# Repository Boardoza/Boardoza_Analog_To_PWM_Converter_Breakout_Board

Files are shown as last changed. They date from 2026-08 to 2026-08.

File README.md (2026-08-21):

# Boardoza Analog To PWM Converter Breakout Board

The **Boardoza Analog to PWM Converter Breakout Board** is a high-precision signal conditioning board designed to convert an analog voltage input into a proportional **PWM (Pulse Width Modulation)** output signal where the **duty cycle increases or decreases proportionally with the applied input voltage**. Built using high-speed operational amplifiers and comparators, this board operates entirely through dedicated hardware circuitry, enabling ultra-fast response times and reliable signal conversion without requiring any firmware or software processing.

This breakout board is ideal for **motor control systems, throttle signal conversion, industrial automation, power electronics, robotics, and embedded analog control applications**. Its low-latency architecture and robust analog signal path make it suitable for safety-critical and noise-sensitive environments where deterministic signal behavior is essential.

## [Click here to purchase!](https://www.ozdisan.com/ureticiler/boardoza)

|Front Side|Back Side|
|:---:|:---:|
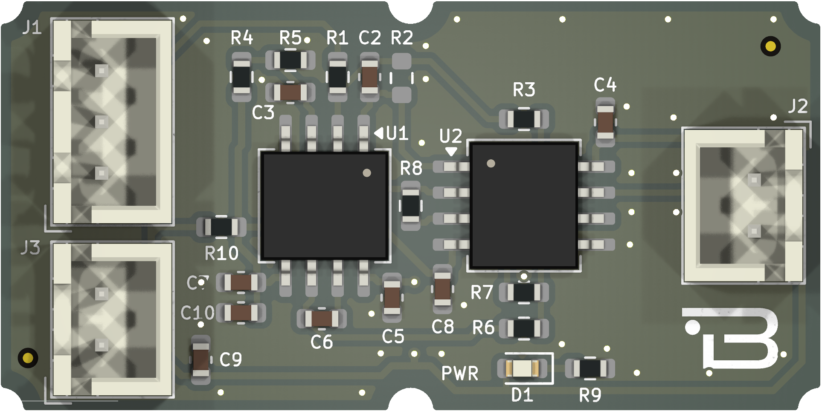
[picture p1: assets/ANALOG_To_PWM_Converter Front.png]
Analog-To-PWM Front
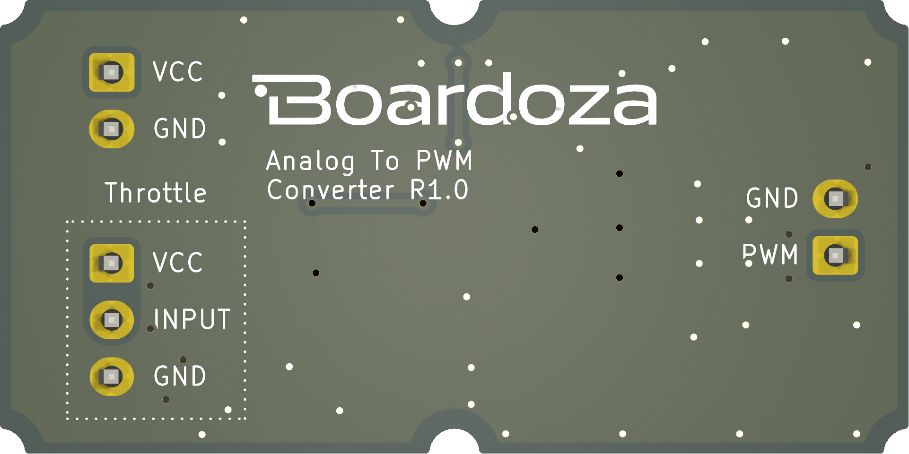
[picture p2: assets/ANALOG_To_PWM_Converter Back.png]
Analog-To-PWM Back
| | |

---

## Key Features

- **Hardware-Based PWM Generation:** Converts analog voltage signals directly into PWM output without requiring a microcontroller.
- **Discrete Analog Design:** Built using precision operational amplifiers and comparators for stable and deterministic operation.
- **Low Latency Signal Path:** Near-instantaneous analog-to-PWM conversion suitable for real-time control systems.
- **Push-Pull CMOS Output:** Provides strong and clean logic-level PWM output compatible with many digital systems.
- **High Noise Immunity:** Reliable operation in electrically noisy environments such as motor drivers and industrial systems.

---

## Technical Specifications

**Model:** Analog to PWM Converter  
**Manufacturer:** Boardoza   
**Manufacturer IC:** Texas Instruments   
**Operational Amplifier Model:** OPA2356  
**Board Type:** Analog Signal Converter    
**Input Voltage (VCC):** 2.7V – 5.5V  
**Analog Input Range:** 0.1V – 4.9V  
**Output Type:** 20kHz PWM (Push-Pull CMOS Logic)  
**Comparator Type:** High-Speed Comparator with Integrated Reference  
**Operational Amplifier Type:** Rail-to-Rail High-Speed Op-Amp  
**Output Short Circuit Current:** 74mA  
**Operating Temperature:** -40°C to +125°C  
**Board Dimensions:** 40mm x 20mm  v

---

## Simulation and Test Results

Simulation and test results are provided below.

| Triangle Wave Output | Error Amplifier Output | PWM Output |
|:---:|:---:|:---:|
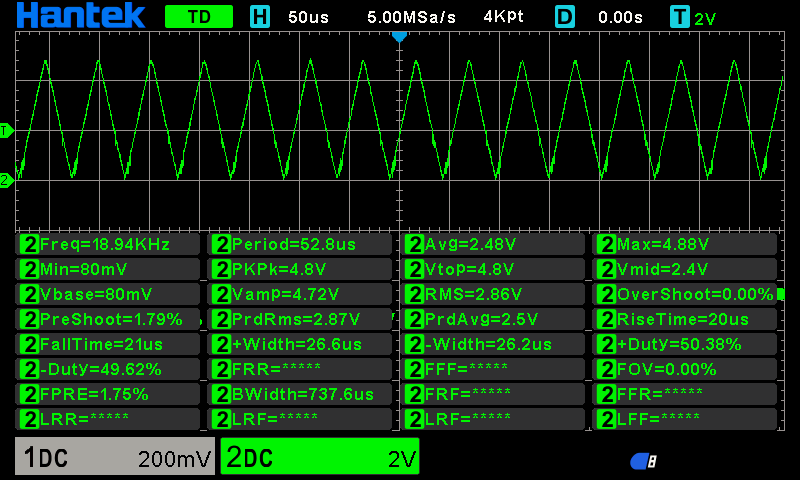
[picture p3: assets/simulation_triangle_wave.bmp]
Triangle Wave Output
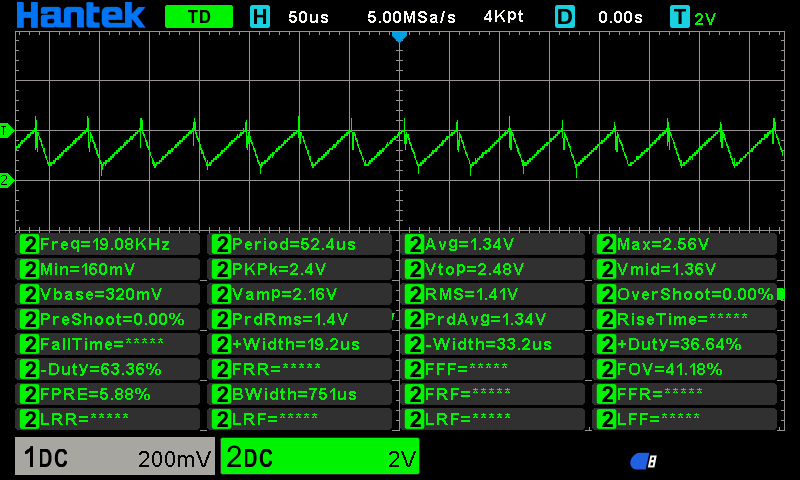
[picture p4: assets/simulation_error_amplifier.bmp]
Error Amplifier Output
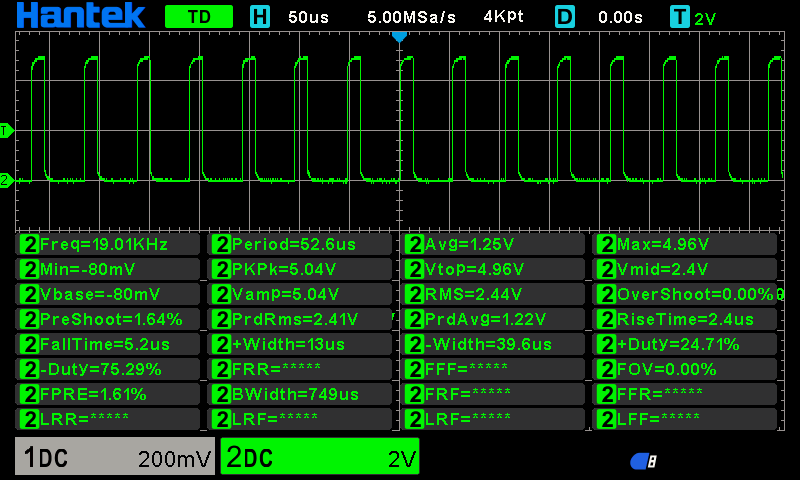
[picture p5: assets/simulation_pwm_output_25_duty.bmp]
PWM Output
|  |  |  |

| Input 100mV | Input 3.3V |
|:---:|:---:|
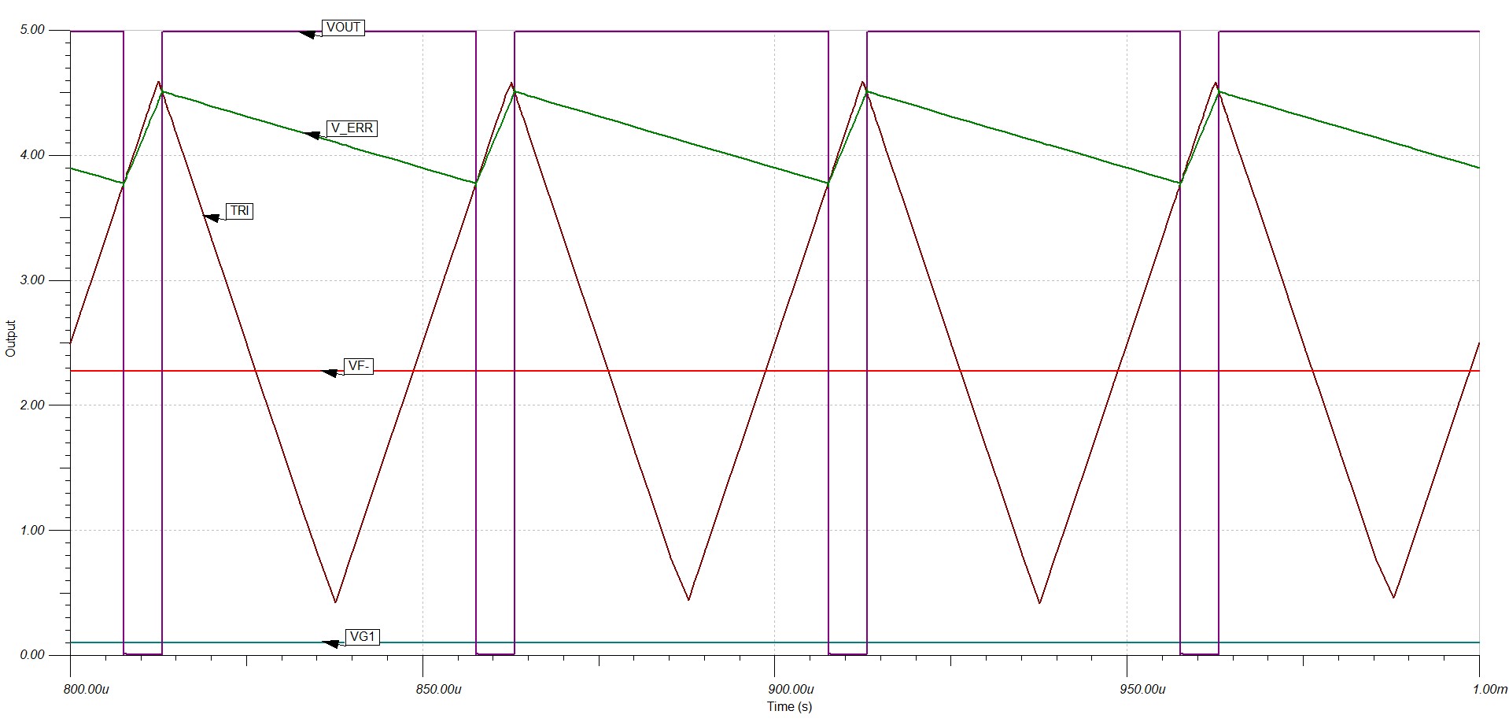
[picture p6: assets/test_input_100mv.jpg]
Input 100mV
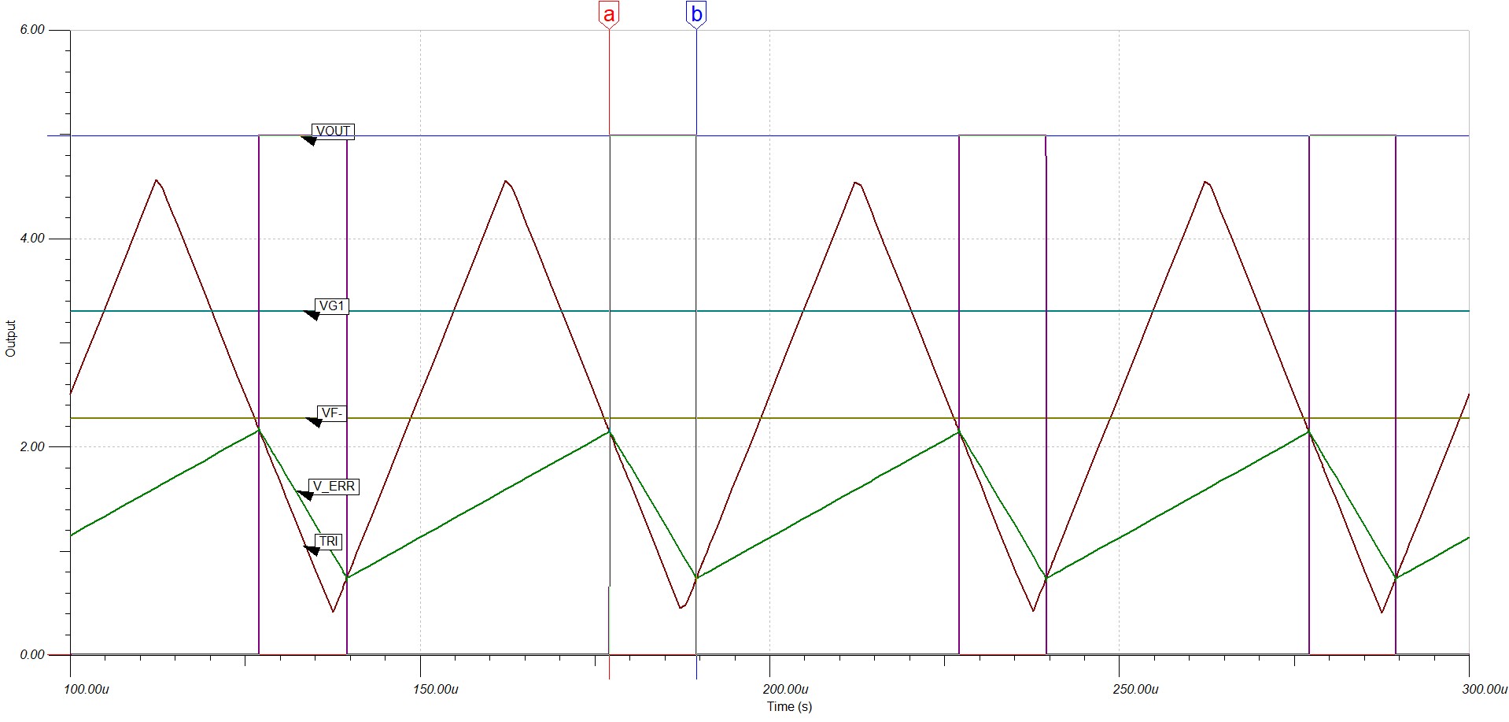
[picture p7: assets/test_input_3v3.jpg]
Input 3.3V
|  |  |

---

## Board Pinout

### ( J1 ) Power & Analog Input Connector

| Pin Number | Pin Name | Description |
|:---:|:---:|---|
| 1 | VCC | Power Supply Input |
| 2 | INPUT | Analog Voltage Input / Throttle Signal |
| 3 | GND | Ground |

### ( J2 ) PWM Output Connector

| Pin Number | Pin Name | Description |
|:---:|:---:|---|
| 1 | VCC | Power Supply Input |
| 2 | GND | Ground |

---

## Board Dimensions

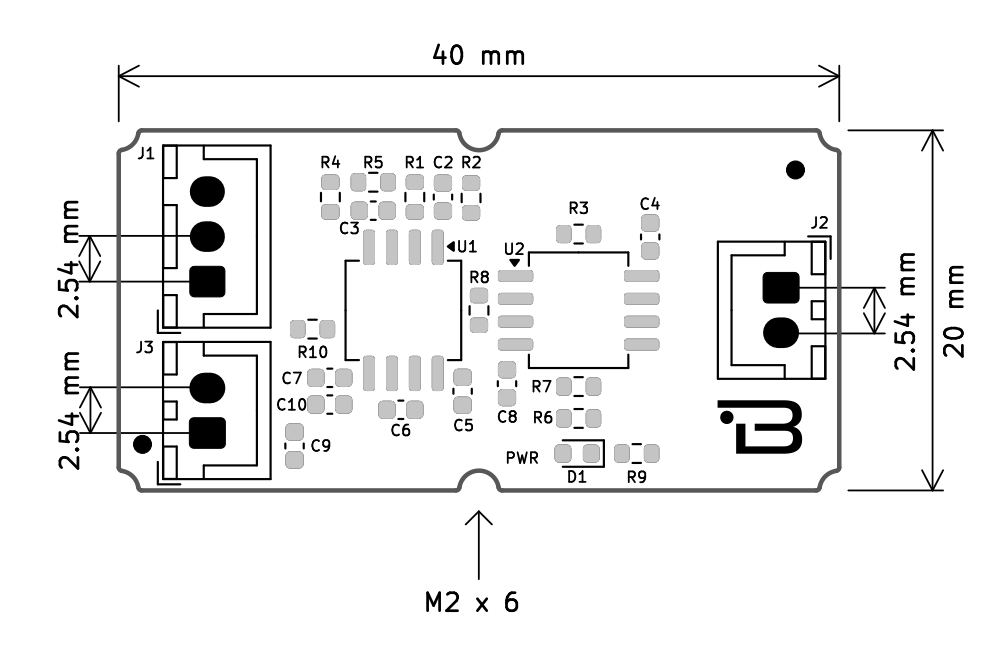
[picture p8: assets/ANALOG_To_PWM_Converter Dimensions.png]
Analog-To-PWM Converter Dimensions


---

## Step Files

[Boardoza ANALOG to PWM Converter.step](./assets/ANALOG_To_PWM_Converter%20Step.step)

---

## Datasheet

[OPA2356 Datasheet.pdf](./assets/OPA2356xxD%20Datasheet.pdf)

[TLV3052 Datasheet.pdf](./assets/TLV3052AID%20Datasheet.pdf)

---

## Version History

- V1.0.0 - Initial Release

---

## Support

- If you have any questions or need support, please contact support@boardoza.com

---

## **License**
### **Hardware Design**

[][cc-by-sa]

All hardware design files are licensed under [Creative Commons Attribution-ShareAlike 4.0 International License][cc-by-sa].

[cc-by-sa]: http://creativecommons.org/licenses/by-sa/4.0/
[cc-by-sa-shield]: https://img.shields.io/badge/License-CC%20BY--SA%204.0-lightgrey.svg

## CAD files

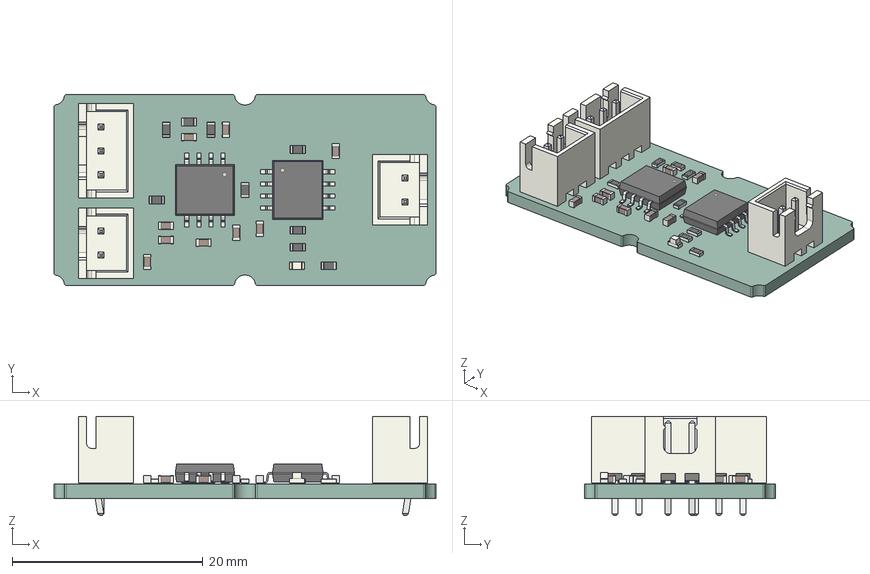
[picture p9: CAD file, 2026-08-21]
assets/ANALOG_To_PWM_Converter Step.step
40.0 x 20.0 x 10.4 mm
JST_XH_B3B-XH-A_1x03_P2.50mm_Vertical
JST_XH_B2B-XH-A_1x02_P2.50mm_Vertical x 2
R_0603_1608Metric x 9
C_0603_1608Metric x 9
LED_0603_1608Metric
SOIC-8_5.3x6.2mm_P1.27mm x 2
kibot_uvh37133_PCB

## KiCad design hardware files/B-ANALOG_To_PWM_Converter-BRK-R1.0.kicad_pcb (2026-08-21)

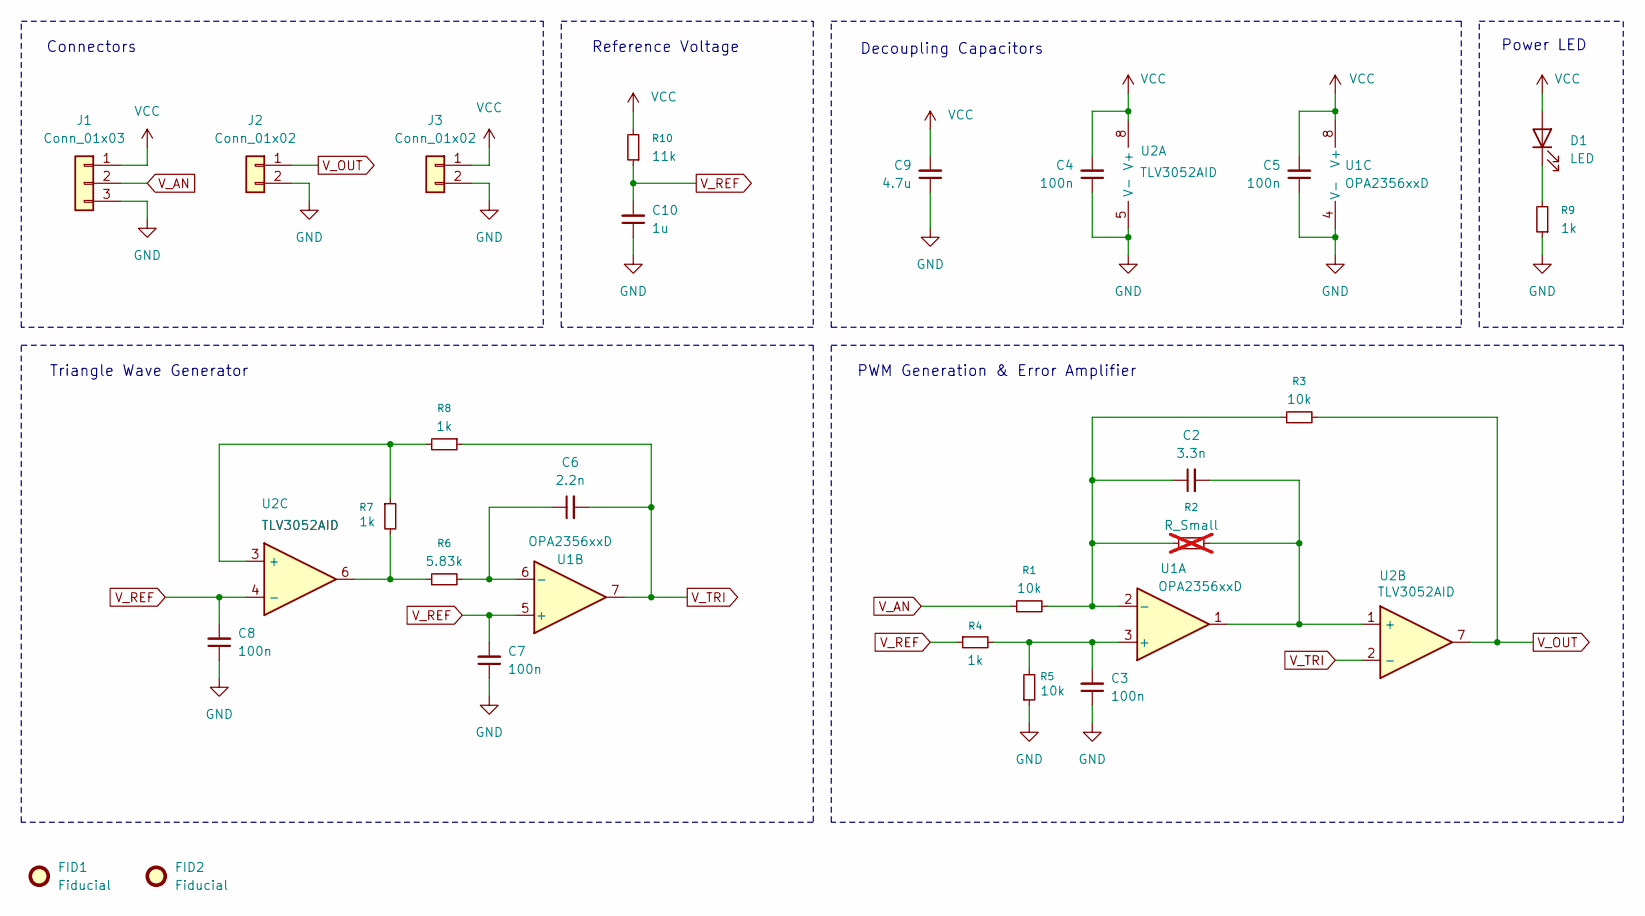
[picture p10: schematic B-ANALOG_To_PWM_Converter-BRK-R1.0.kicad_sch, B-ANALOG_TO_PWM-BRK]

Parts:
C2: 3.3n; C_0603_1608Metric; MPN CL10C332JA8NNNC
C3, C4, C5, C7, C8: 100n; C_0603_1608Metric; MPN CC0603KRX7R9BB104
C6: 2.2n; C_0603_1608Metric; MPN CL10C222JB8NNNC
C9: 4.7u; C_0603_1608Metric; MPN CL10A475KP8NNNC
C10: 1u; C_0603_1608Metric; MPN CL10B105KO8NNNC
D1: LED; LED_0603_1608Metric; MPN LTST-C190KRKT
FID1, FID2: Fiducial; Fiducial_0.5mm_Mask1mm
J1: Conn_01x03; JST_XH_B3B-XH-A_1x03_P2.50mm_Vertical; MPN L-KLS1-2.50-03-SB
J2, J3: Conn_01x02; JST_XH_B2B-XH-A_1x02_P2.50mm_Vertical; MPN L-KLS1-2.50-02-SB
R1, R3, R5: 10k; R_0603_1608Metric; MPN TC0350B1002T5F
R2: R_Small; R_0603_1608Metric; not fitted
R4, R7, R8, R9: 1k; R_0603_1608Metric; MPN TC0325D1001T5C
R6: 5.83k; R_0603_1608Metric; MPN RN73R1JTTD5831B25
R10: 11k; R_0603_1608Metric; MPN ERJPB3B1102V
U1: OPA2356xxD; SOIC-8_5.3x6.2mm_P1.27mm; MPN OPA2356AID
U2: TLV3052AID; SOIC-8_5.3x6.2mm_P1.27mm; MPN TLV3502AID

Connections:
GND: C3.1, C4.1, C5.1, C7.1, C8.1, C9.1, C10.1, J1.3, J2.2, J3.2, R5.1, R9.1, U1.4 (V-), U2.5 (V-)
unnamed: D1.1 (K), R9.2
unnamed: R6.1, R7.2, U2.6
unnamed: C3.2, R4.2, R5.2, U1.3 (+)
unnamed: C2.1, R1.2, R2.1, R3.1, U1.2 (-)
unnamed: C6.1, R6.2, U1.6 (-)
unnamed: C2.2, R2.2, U1.1, U2.1 (+)
unnamed: R7.1, R8.2, U2.3 (+)
VCC: C4.2, C5.2, C9.2, D1.2 (A), J1.1, J3.1, R10.2, U1.8 (V+), U2.8 (V+)
V_AN: J1.2, R1.1
V_OUT: J2.1, R3.2, U2.7
V_REF: C7.2, C8.2, C10.2, R4.1, R10.1, U1.5 (+), U2.4 (-)
V_TRI: C6.2, R8.1, U1.7, U2.2 (-)

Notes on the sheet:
Connectors
Triangle Wave Generator
Power LED
Reference Voltage
Decoupling Capacitors
PWM Generation & Error Amplifier

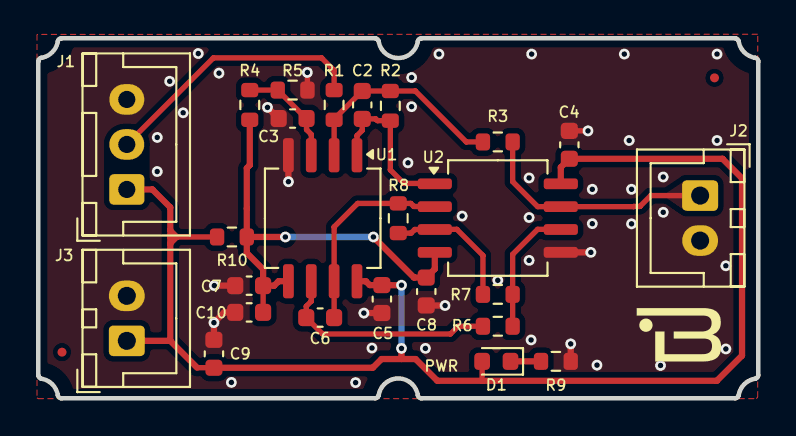
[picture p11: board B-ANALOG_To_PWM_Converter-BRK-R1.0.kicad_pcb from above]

Board: 2 copper layers, 40.0 x 20.0 mm, 27 parts (0 on the bottom side), 13 nets.

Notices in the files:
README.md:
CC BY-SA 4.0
